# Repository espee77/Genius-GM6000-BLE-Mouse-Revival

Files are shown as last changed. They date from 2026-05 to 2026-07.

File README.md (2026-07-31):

# Reviving a Classic: Genius GM-6000 Wireless BLE / Wired USB / Air Mouse Conversion

This project is an open-source hardware and firmware conversion for the classic Genius GM-6000 mechanical ball mouse.



## History

Introduced in the late 1980s, the Genius GM-6000 was one of the flagship serial mice from [KYE Systems](https://www.geniusnet.com/en) under its Genius brand. At a time when the computer mouse was becoming an essential PC peripheral, the [Genius GM-6000](http://www.tcocd.de/Pictures/Peripheral/Genius/Genius.shtml) stood out with its robust optomechanical design, dynamic resolution technology, and support for both Microsoft and Mouse Systems serial protocols. Bundled with graphics software including Menu Maker and Dr. Halo/Dr. Genius, it was marketed as a premium mouse for both business and graphics applications.

By 1989, Genius advertisements described the company as "the largest selling mouse in Europe," with the GM-6000 featured prominently in its international marketing campaigns. Contemporary reviews also praised the mouse for its accuracy, compatibility, and comprehensive software bundle.

More than three decades later, the GM-6000 is still appreciated by collectors and retro-computing enthusiasts for its solid construction and durable mechanical tracking system. This project preserves those original mechanics while replacing the obsolete electronics with modern Bluetooth Low Energy technology, a rechargeable battery, and optional Air Mouse functionality.

---

## The Goal

The goal of this project is to preserve the look, feel, and mechanics of the original Genius GM-6000 while replacing its obsolete electronics with a modern Bluetooth Low Energy (BLE) system and adding Air Mouse functionality.

Genius-GM6000

Instead of replacing the original ball mechanism with a modern optical sensor, this project preserves the original encoder wheels and tracking mechanics. A custom infrared optical detection system using IR LEDs and phototransistors reads the original quadrature encoders, maintaining the unique feel and behavior of the original mouse.

At the heart of the conversion is a custom PCB based on the [**Seeed Studio XIAO nRF52840 Sense**](https://wiki.seeedstudio.com/XIAO_BLE/), providing Bluetooth LE connectivity, rechargeable Li-Po battery support, intelligent power management, and modern firmware—all while fitting completely inside the original mouse shell.

Genius-GM6000

If this project inspires someone to restore vintage hardware, learn electronics, or build an even better version, then it has already achieved its goal. Contributions, suggestions, forks, and improvements are always welcome.

---

# Project Goals

* Preserve the original appearance of the mouse
* Preserve the original ball and encoder mechanics
* Replace the original electronics with a modern custom PCB
* Add wireless Bluetooth Low Energy (BLE) connectivity
* Integrate a rechargeable Li-Po battery
* Keep both hardware and firmware fully open source

Genius-GM6000

---

# Features

## Ball Mouse

* Bluetooth Low Energy (BLE) HID and wired USB HID support
* Original mechanical ball tracking
* Original infrared quadrature encoder system
* Adjustable cursor speed
* Three original mouse buttons
* Hold the middle button while moving the mouse to scroll smoothly
* Independent sensitivity settings for BLE and USB modes

## Air Mouse

* Automatic Air Mouse mode in both BLE and USB operation
* Automatic switching based on mouse orientation
* Motion smoothing, tremor reduction, and spike filtering
* Full button support while in Air Mouse mode

## Bluetooth

* Compatible with Windows, macOS, Linux, Android, and iPadOS
* Automatic BLE reconnection
* Bluetooth Battery Service (battery level reporting)
* Optimized BLE connection parameters for responsive cursor movement

## Power Management

* Rechargeable Li-Po battery
* Intelligent multi-stage power management
* Automatic IR LED power control
* Light Sleep and Deep Sleep modes for maximum battery life
* Automatic wake-up from movement, IMU motion (during Light Sleep), or button press (from Deep Sleep)

## Hardware

* Custom PCB designed specifically for the GM-6000
* Based on the Seeed Studio XIAO nRF52840 Sense
* Preserves the original buttons and tracking hardware
* Compact design that fits completely inside the original enclosure

---

# Using the Mouse

Despite its modern electronics, the converted GM-6000 is designed to preserve the familiar feel of the original mouse while adding modern wireless features and intelligent power management.

## Ball Mouse

The original mechanical ball, encoder wheels, and tracking mechanism are fully preserved. Cursor movement is generated from the original quadrature encoders, maintaining the characteristic feel of the original GM-6000.

## Scrolling

Since the original mouse has no scroll wheel, scrolling is performed by holding the **middle mouse button** while moving the mouse forward or backward. This allows smooth scrolling without altering the mouse's original appearance.

## Air Mouse

Rotating the mouse onto its side automatically activates **Air Mouse Mode**. The built-in IMU controls the cursor, making the mouse suitable for presentations or media control.

Switching between Ball Mouse and Air Mouse modes is completely automatic—no switches or software are required.

## USB & Bluetooth

The mouse operates as both a wired USB mouse and a Bluetooth Low Energy mouse. Connecting a USB cable automatically enables wired operation, while disconnecting it returns the mouse to Bluetooth mode.

## Intelligent Sleep Modes

To maximize battery life, the firmware automatically manages power consumption.

| Mode | Description |
|---|---|
| **Active** | Full performance while the mouse is in use. |
| **Light Sleep** | Infrared tracking is powered down while remaining ready to wake almost instantly. |
| **Deep Sleep** | Bluetooth disconnects and the mouse enters its lowest power state. |

The mouse automatically wakes from movement, IMU motion (during Light Sleep), or a button press (from Deep Sleep).

## Battery

Battery level is continuously monitored and reported through the Bluetooth Battery Service, allowing supported operating systems to display the remaining battery percentage.

## Factory Reset

If you experience Bluetooth pairing or connection problems, the firmware includes a built-in **Factory Reset** function.

With the mouse powered off, press and hold the **left**, **middle**, and **right** mouse buttons simultaneously while turning the mouse on. Keep all three buttons pressed for approximately **5 seconds** until the status LEDs indicate that the reset has started. The mouse will erase all stored Bluetooth pairing information, saved settings, usage statistics, battery statistics, and internal storage before automatically rebooting.

After a Factory Reset, remove the mouse from your computer's Bluetooth device list (if previously paired) and pair it again as a new device.

---

# Repository Contents

* [Firmware Installation Manual](Firmware%20installation%20manual.md)
* [Bill of material](https://github.com/espee77/Genius-GM6000-BLE-Mouse-Revival/blob/main/V1.0/Bill%20of%20Materials%20(BOM))
* [KiCad 10 project files](https://github.com/espee77/Genius-GM6000-BLE-Mouse-Revival/tree/main/V1.0/KICAD)
* [Schematics](https://github.com/espee77/Genius-GM6000-BLE-Mouse-Revival/tree/main/V1.0/Schematic)
* [Datasheets](https://github.com/espee77/Genius-GM6000-BLE-Mouse-Revival/tree/main/V1.0/Datasheets)
* [Firmware source code](https://github.com/espee77/Genius-GM6000-BLE-Mouse-Revival/tree/main/V1.01/Firmware)
* [JLCPCB zip file for board ordering](https://github.com/espee77/Genius-GM6000-BLE-Mouse-Revival/tree/main/V1.0/JLCPCB)
* [3D CAD files](https://github.com/espee77/Genius-GM6000-BLE-Mouse-Revival/tree/main/V1.0/3D%20files/Step214)
* [Pictures with assembly notes](https://github.com/espee77/Genius-GM6000-BLE-Mouse-Revival/tree/main/V1.0/Pictures%20with%20assembly%20notes)

---

# Why Open Source?

This project started as a fun way to combine retro hardware with modern electronics while preserving a classic piece of computer history.

By making both the hardware and firmware open source, I hope others can learn from it, improve the design, or use it as the foundation for their own retro hardware projects.

Contributions are always welcome, whether they involve hardware improvements, firmware development, documentation, testing, or entirely new ideas.

---

# Current Status

- **[V1.0 – Stable Release](https://github.com/espee77/Genius-GM6000-BLE-Mouse-Revival/tree/main/V1.01)**
- Second-generation custom PCB completed
- Stable Bluetooth Low Energy (BLE) HID firmware
- Reliable deep-sleep wake and automatic BLE reconnection
- Ball Mouse mode fully functional
- Air Mouse mode fully functional
- USB wired mouse mode implemented
- Battery monitoring and charging support
- Automatic power management with multi-stage sleep modes
- Built-in Factory Reset and diagnostic tools
- Extensively tested in daily use
- Optimized Bluetooth performance, responsiveness, and power consumption

---

# Disclaimers

* This is an experimental hobby project.
* Use the provided files and information entirely at your own risk.
* Li-Po batteries and electronic modifications can be hazardous if handled improperly. Always follow appropriate safety precautions.
* This hardware will not fit the Genius GM-6 which differs slightly from the GM-6000 (encoder positions, contact roller size, and rear switch).

---
Genius-GM6000

# Acknowledgements

This project is an independent, community-created restoration effort. The CAD models were created by measuring an original Genius GM-6000 mouse and are not based on or derived from original manufacturer CAD data. "Genius" is a trademark of its respective owner and is used solely to identify the compatible product.
Special thanks to the retro hardware, maker, and open-source communities whose shared knowledge, documentation, and projects made this conversion possible.



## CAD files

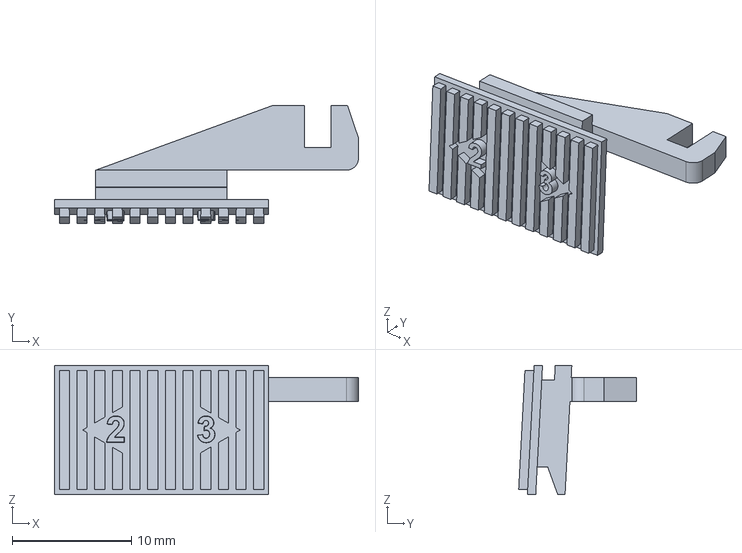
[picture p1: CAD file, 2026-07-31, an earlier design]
V1.0/3D files/Step214/Genius_GM-6000_Slide_Button_V0.1.stp
25.4 x 9.85 x 10.8 mm

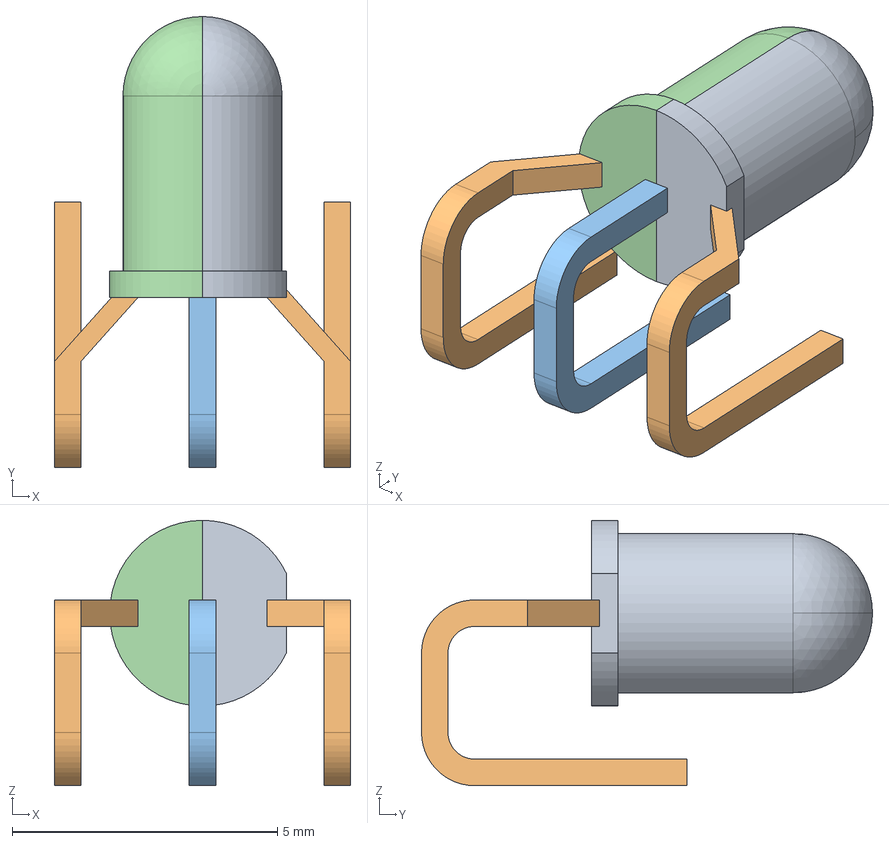
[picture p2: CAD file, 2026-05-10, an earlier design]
V1.0/KICAD/3D data/Genius_GM-6000_BLE_LED_3009R1B2C-DSA_V0.1.stp
5.58 x 8.50 x 5.00 mm

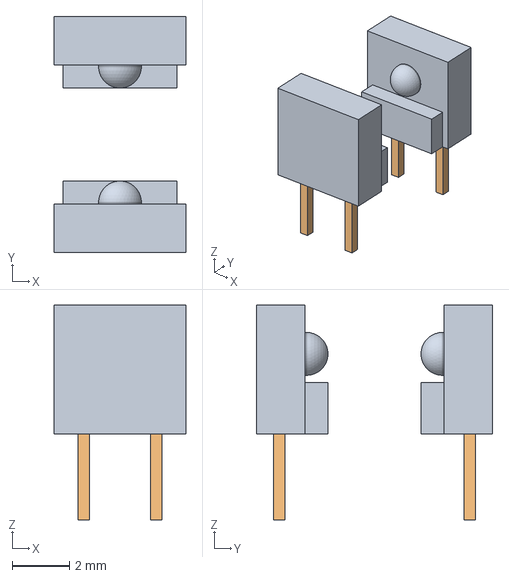
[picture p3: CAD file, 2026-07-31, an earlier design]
V1.0/3D files/Step214/Genius_GM-6000_IR928_PT928_V0.1.stp
4.60 x 8.25 x 7.50 mm

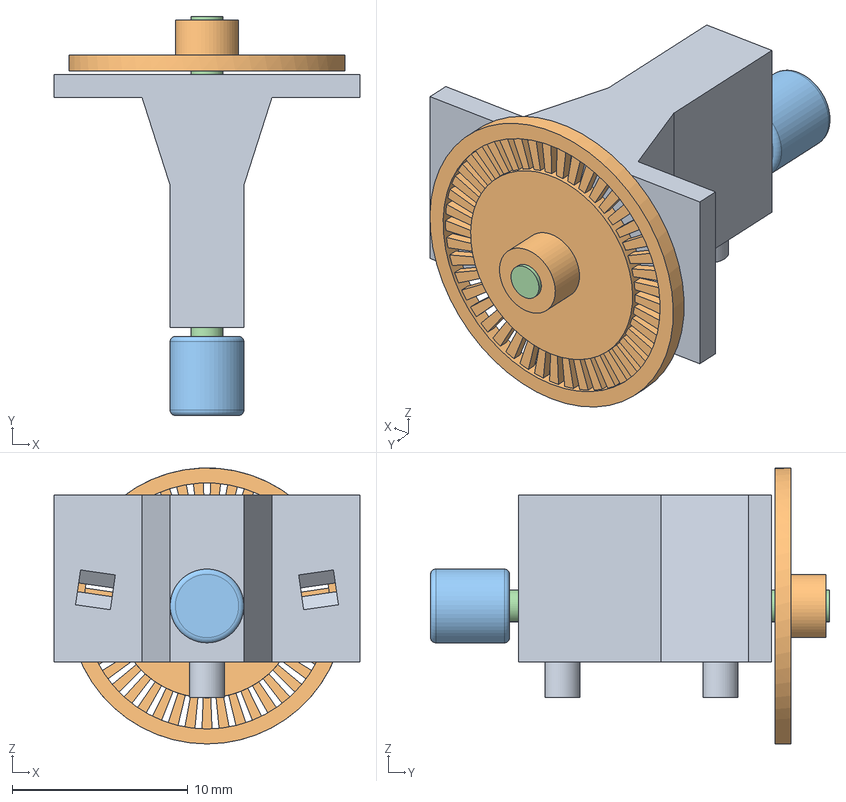
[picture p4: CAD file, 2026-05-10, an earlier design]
V1.0/KICAD/3D data/Genius_GM-6000_Encoder_Wheel_V0.1.stp
17.4 x 22.7 x 15.7 mm

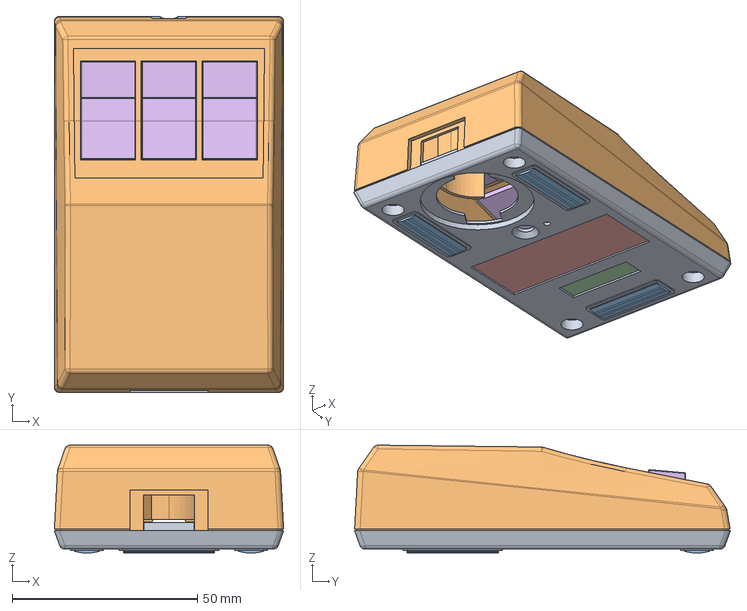
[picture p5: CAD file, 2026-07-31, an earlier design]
V1.0/3D files/Step214/Genius_GM-6000_Housing_V0.3.stp
62.0 x 101.6 x 29.1 mm

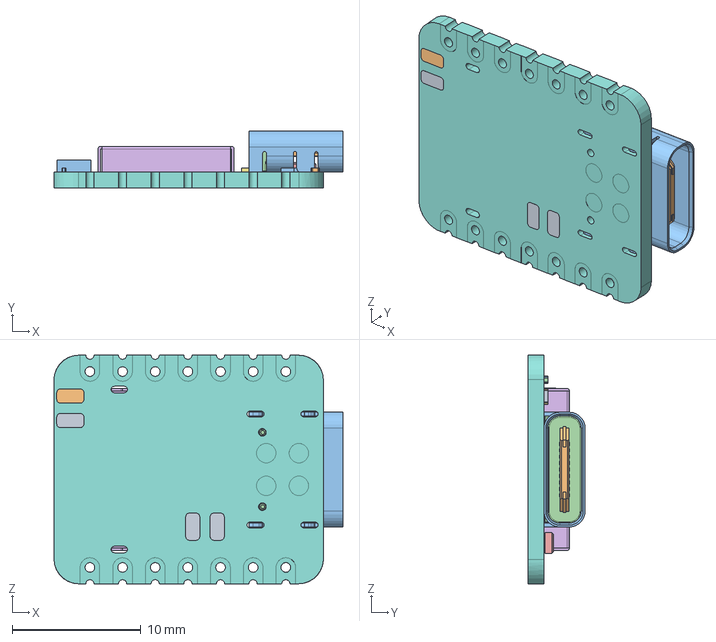
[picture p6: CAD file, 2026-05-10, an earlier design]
V1.0/KICAD/3D data/Genius_GM-6000_XIAO-nRF52840_Sense_V0.1.stp
22.5 x 4.46 x 17.8 mm

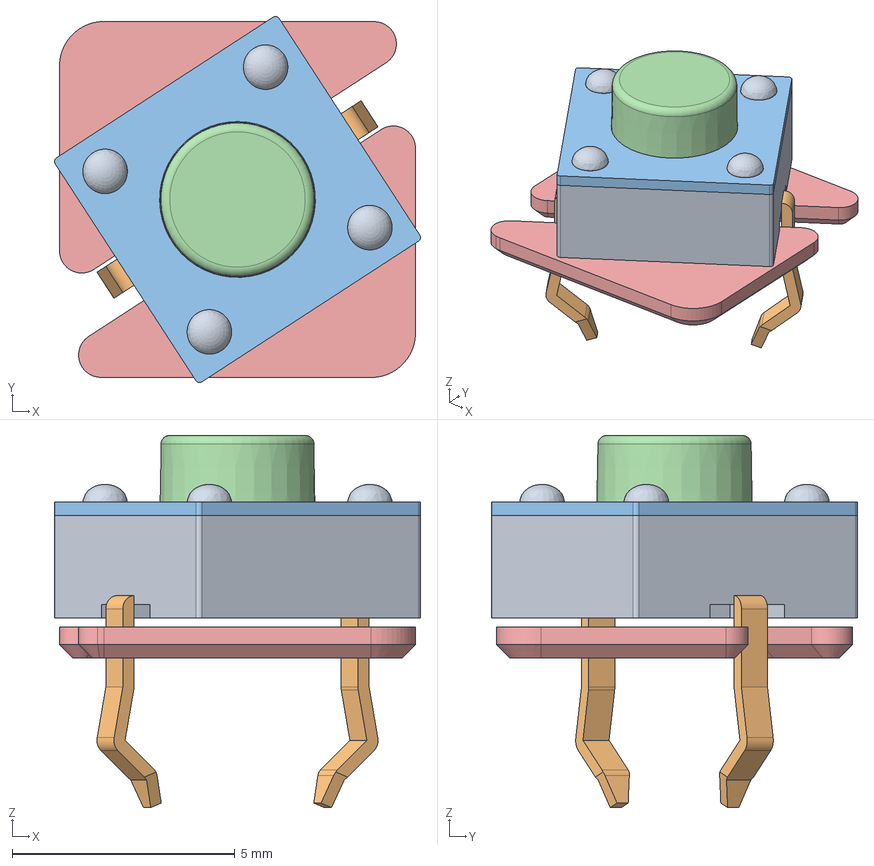
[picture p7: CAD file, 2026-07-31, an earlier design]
V1.0/3D files/Step214/Genius_GM-6000_Tact_Switch_Silent_6x6_V0.1.stp
8.22 x 8.22 x 8.36 mm

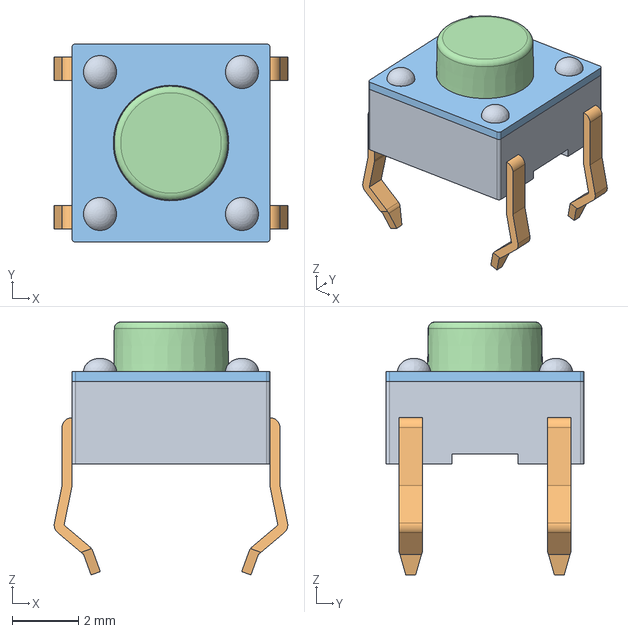
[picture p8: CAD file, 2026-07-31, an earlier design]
V1.0/3D files/Step214/Genius_GM-6000_Tact_Switch_4.3_6x6_V0.1.stp
7.08 x 6.00 x 7.66 mm

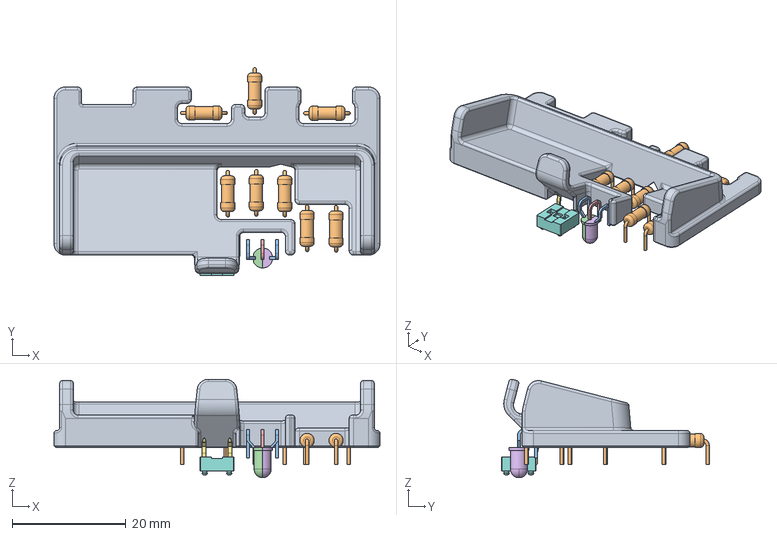
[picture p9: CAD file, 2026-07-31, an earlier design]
V1.0/3D files/Step214/Genius_GM-6000_LiPo_Holder_V0.1.stp
57.2 x 36.4 x 17.3 mm

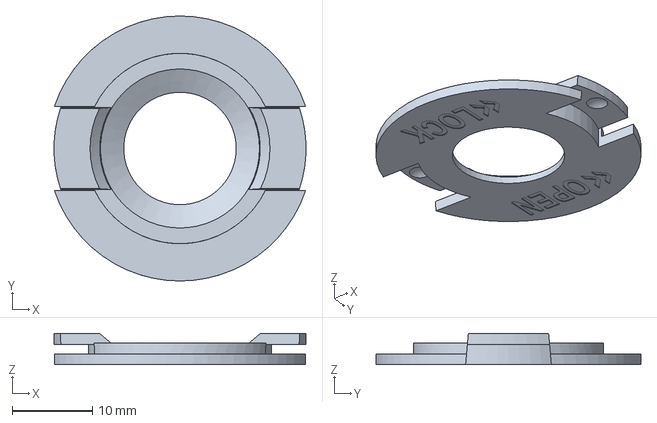
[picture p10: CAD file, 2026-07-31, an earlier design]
V1.0/3D files/Step214/Genius_GM-6000_Ball_Lock_V0.1.stp
31.4 x 33.0 x 3.90 mm

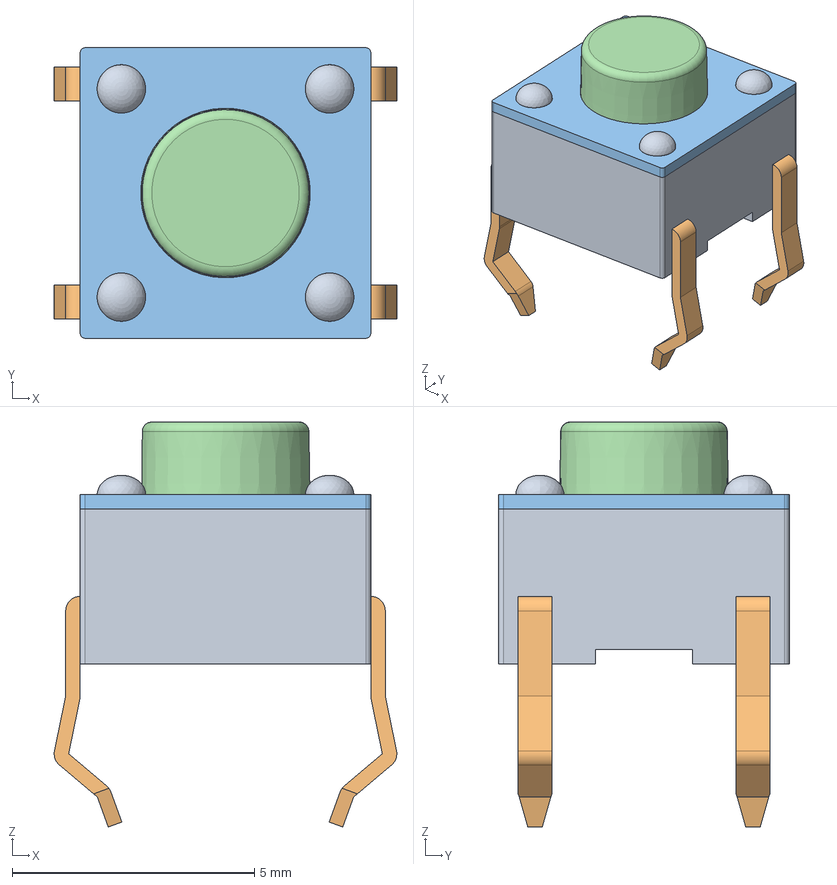
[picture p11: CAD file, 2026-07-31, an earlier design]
V1.0/3D files/Step214/Genius_GM-6000_Tact_Switch_5.0_6x6_V0.1.stp
7.08 x 6.00 x 8.36 mm

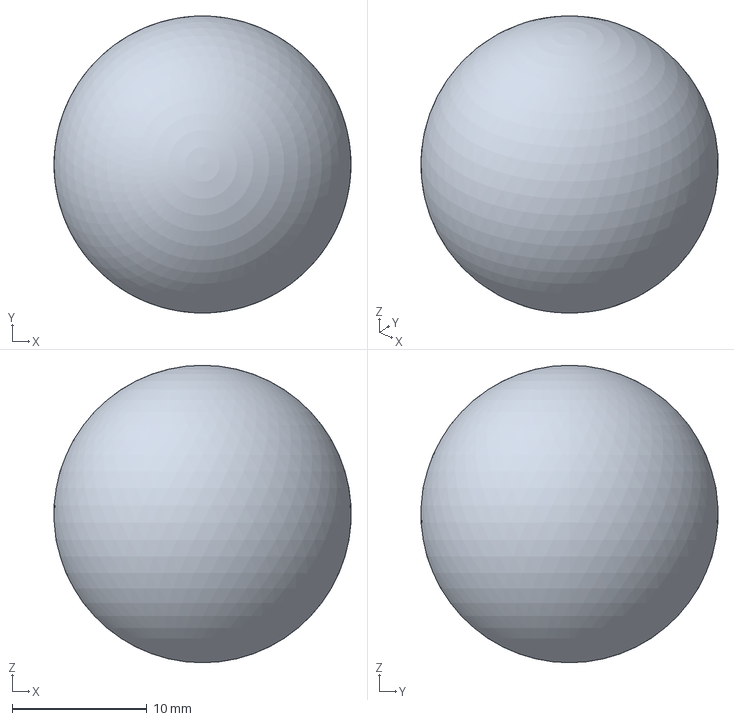
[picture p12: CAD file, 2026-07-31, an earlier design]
V1.0/3D files/Step214/Genius_GM-6000_Ball_V0.1.stp
22.1 x 22.1 x 22.1 mm

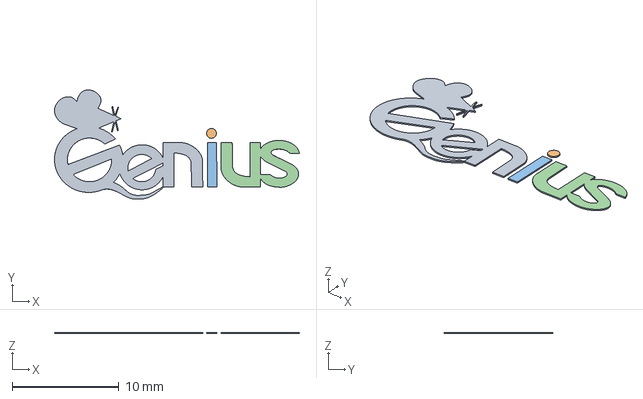
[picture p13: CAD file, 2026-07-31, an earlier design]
V1.0/3D files/Step214/Genius_GM-6000_Logo_V0.1.stp
23.0 x 10.2 x 0.108 mm

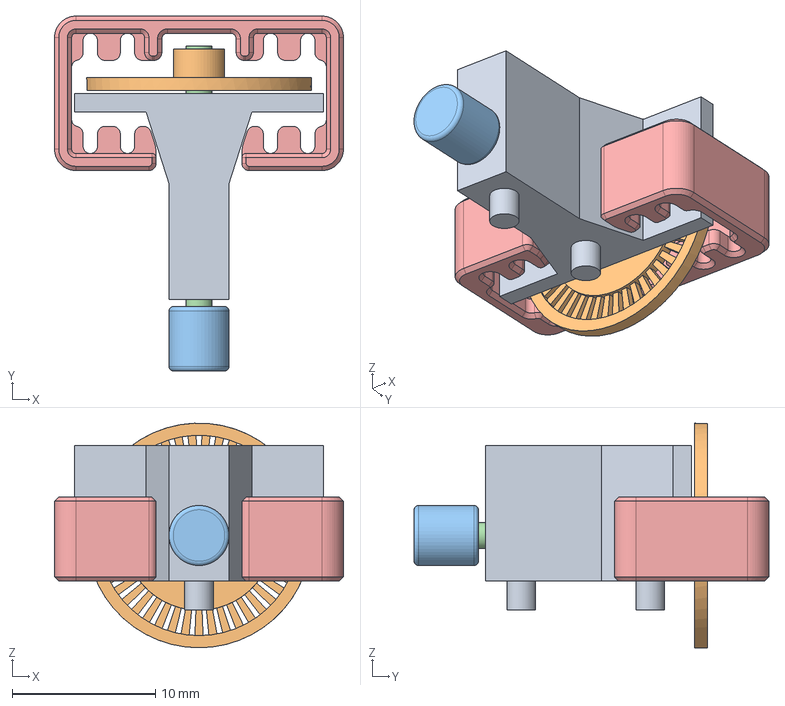
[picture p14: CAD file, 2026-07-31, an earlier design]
V1.0/3D files/Step214/Genius_GM-6000_Encoder_Wheel_V0.2.stp
20.2 x 24.8 x 15.7 mm

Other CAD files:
V1.0/3D files/Step214/Genius_GM-6000_Assy_V1.0.stp
V1.0/3D files/Step214/Genius_GM-6000_XIAO-nRF52840_Sense_V0.1.stp
V1.0/3D files/Step214/Genius_GM-6000_Switch_SS-12D07-VG-4-NS-GA-PA_V0.1.stp
V1.0/3D files/Step214/Genius_GM-6000_BLE_LED_3009R1B2C-DSA_V0.1.stp
V1.0/3D files/Step214/Genius_GM-6000_LiPo_Cardo_Scala_Rider_G4_800mAh_V0.1.stp

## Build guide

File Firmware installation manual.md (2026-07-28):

# Installing the GM-6000 Firmware

> [!IMPORTANT]
> This guide is for the **Genius GM-6000 BLE Mouse Revival** project using the **Seeed Studio XIAO nRF52840 Sense**.
>
> It assumes you are using **Windows 10 or Windows 11**.

This guide explains how to install the latest firmware on your GM-6000 mouse using PlatformIO.

**No programming experience is required.**

> [!NOTE]
> **Tested with**
>
> * Windows 11
> * Visual Studio Code 1.104 or newer
> * PlatformIO IDE 3.x

---

## Table of Contents

* [What You Need](#requirements)
* [Step 1 – Install Visual Studio Code](#install-vscode)
* [Step 2 – Install PlatformIO](#install-platformio)
* [Step 3 – Download the Firmware](#download-firmware)
* [Step 4 – Extract the ZIP File](#extract-firmware)
* [Step 5 – Open the Project](#open-project)
* [Step 6 – Connect the Mouse](#connect-mouse)
* [Step 7 – Build the Firmware](#build-firmware)
* [Step 8 – Upload the Firmware](#upload-firmware)
* [Step 9 – Pair the Mouse](#pair-mouse)
* [Reset Bluetooth Pairings](#reset-pairings)
* [Troubleshooting](#troubleshooting)
* [Updating the Firmware](#update-firmware)

---

## What You Need

Before you begin, make sure you have:

* A Windows 10 or Windows 11 computer
* A USB-C **data** cable
* An internet connection
* The latest GM-6000 firmware ZIP file

> [!NOTE]
> Some USB-C cables only provide power. If the mouse is not detected, try another cable.

[Back to Table of Contents](#table-of-contents)

---

## Step 1 – Install Visual Studio Code

PlatformIO runs inside Visual Studio Code.

1. Download [Visual Studio Code](https://code.visualstudio.com/download) from the official website.

2. Run the installer.

3. Accept the default installation settings.

4. Start Visual Studio Code.

> [!IMPORTANT]
> Install **Visual Studio Code**.
>
> Do **not** install the larger application called **Visual Studio**.

[Back to Table of Contents](#table-of-contents)

---

## Step 2 – Install PlatformIO

1. Open Visual Studio Code.

2. Click the **Extensions** icon on the left.

3. Search for:

   ```text
   PlatformIO IDE
   ```

4. Select **PlatformIO IDE** by **PlatformIO**.

5. Click **Install**.

6. Wait for the installation to finish.

7. Restart Visual Studio Code if prompted.

See the official [PlatformIO installation guide](https://platformio.org/install/ide?install=vscode).

> [!TIP]
> You do **not** need to install Python or the Arduino IDE separately.

[Back to Table of Contents](#table-of-contents)

---

## Step 3 – Download the Firmware

Download the latest firmware ZIP file from the project’s **GitHub Releases** page.

Save the ZIP file somewhere easy to find, such as your **Downloads** folder.

[Back to Table of Contents](#table-of-contents)

---

## Step 4 – Extract the ZIP File

Do **not** open the project directly from the ZIP file.

1. Right-click the downloaded ZIP file.

2. Select **Extract All...**

3. Choose a location, for example:

   ```text
   Documents\GM-6000 Firmware
   ```

4. Click **Extract**.

[Back to Table of Contents](#table-of-contents)

---

## Step 5 – Open the Project

1. Open Visual Studio Code.

2. Select:

   **File → Open Folder...**

3. Browse to the extracted firmware folder.

4. Select the folder containing:

   ```text
   platformio.ini
   ```

5. Click **Select Folder**.

6. If Visual Studio Code asks whether you trust the project, click:

   **Trust the Authors**

> [!TIP]
> If you cannot find `platformio.ini`, you probably opened the wrong folder.

The correct project folder should contain files and folders similar to these:

```text
platformio.ini
src
include
lib
```

[Back to Table of Contents](#table-of-contents)

---

## Step 6 – Connect the Mouse

1. Connect the mouse to your computer using a USB-C **data** cable.

2. Turn the mouse on.

Windows should detect the mouse automatically.

[Back to Table of Contents](#table-of-contents)

---

## Step 7 – Build the Firmware

Building the project checks that everything is ready before uploading.

**It does not change anything on the mouse.**

### Method 1 – Project Tasks

1. Click the **PlatformIO** icon, usually shown as an alien-head symbol, in the left sidebar.

2. Expand:

   ```text
   Project Tasks
   ```

3. Expand:

   ```text
   General
   ```

4. Click:

   ```text
   Build
   ```

### Method 2 – Build Button

If a **Build (✓)** button is visible in your PlatformIO interface, you can use that instead.

> [!NOTE]
> The first build may take several minutes.
>
> PlatformIO automatically downloads the compiler, board support package and required libraries during the first build.

When the build finishes successfully, the terminal should end with:

```text
SUCCESS
```

Do **not** continue if the build ends with:

```text
FAILED
```

[Back to Table of Contents](#table-of-contents)

---

## Step 8 – Upload the Firmware

### Method 1 – Project Tasks

1. Open:

   ```text
   Project Tasks
   ```

2. Expand:

   ```text
   General
   ```

3. Click:

   ```text
   Upload
   ```

### Method 2 – Upload Button

If an **Upload (→)** button is visible in your PlatformIO interface, you can use that instead.

PlatformIO will now:

* Build the firmware
* Upload it to the mouse
* Restart the mouse automatically

When the upload is complete, the terminal should end with:

```text
SUCCESS
```

> [!WARNING]
> Do not disconnect the USB cable while the firmware is being uploaded.

[Back to Table of Contents](#table-of-contents)

---

## Step 9 – Pair the Mouse

After uploading:

1. Disconnect the USB cable if you want to use Bluetooth.

2. Turn the mouse off and back on.

3. Open your computer’s Bluetooth settings.

4. Select:

   ```text
   Genius GM-6000 BLE mouse
   ```

5. Complete the pairing process.

Your mouse is now ready to use.

[Back to Table of Contents](#table-of-contents)

---

## Reset Bluetooth Pairings

Use this function if the mouse cannot pair with a new computer or repeatedly connects and disconnects during pairing.

1. Turn the mouse **off**.

2. Press and hold all three mouse buttons:

   * Left mouse button
   * Middle mouse button
   * Right mouse button

3. While holding all three buttons, turn the mouse **on**.

4. Keep holding the buttons for **5 seconds**.

5. Release the buttons.

The mouse will erase all stored Bluetooth pairings and restart automatically.

You can now pair it as a new Bluetooth mouse.

> [!NOTE]
> If your mouse has an external dual-colour status LED installed, the red and blue LEDs will alternate while you hold the buttons.
>
> After the stored pairings have been erased, both colours will flash three times before the mouse restarts.

> [!IMPORTANT]
> You may also need to remove the old mouse entry from your computer’s Bluetooth settings before pairing it again.

[Back to Table of Contents](#table-of-contents)

---

## Troubleshooting

<details>
<summary><strong>The mouse is not detected</strong></summary>

Try the following:

* Make sure you are using a USB-C **data** cable.
* Try another USB port.
* Try another USB cable.
* Disconnect and reconnect the mouse.
* Turn the mouse off and back on.

</details>

<details>
<summary><strong>Enter Bootloader Mode</strong></summary>

If uploading still fails:

1. Leave the mouse connected by USB.

2. Quickly press the **RESET** button on the XIAO **twice**.

3. A new COM port should appear.

4. Try uploading again.

> [!NOTE]
> The COM port number may change when the XIAO enters bootloader mode. This is normal.

See the official [Seeed Studio XIAO nRF52840 documentation](https://wiki.seeedstudio.com/XIAO_BLE/).

</details>

<details>
<summary><strong>PlatformIO reports “Access is denied”</strong></summary>

If you receive an error similar to:

```text
PermissionError: Access is denied
```

Another program is probably already using the serial port.

Close programs such as:

* PlatformIO Serial Monitor
* PuTTY
* Another serial terminal
* Another open instance of Visual Studio Code

Then try uploading again.

</details>

<details>
<summary><strong>PlatformIO uses the wrong COM port</strong></summary>

Normally PlatformIO detects the correct COM port automatically.

If it does not:

1. Open:

   ```text
   platformio.ini
   ```

2. Find or add:

   ```ini
   upload_port =
   ```

3. Set it to the correct COM port, for example:

   ```ini
   upload_port = COM19
   ```

4. Save the file.

5. Try uploading again.

If the COM port changes later, update or remove this line.

> [!NOTE]
> The normal firmware mode and bootloader mode may use different COM port numbers.

</details>

<details>
<summary><strong>The build fails</strong></summary>

If the project does not build:

* Make sure the ZIP file was fully extracted.
* Make sure you opened the folder containing `platformio.ini`.
* Check that your internet connection is working.
* Verify that PlatformIO IDE is installed correctly.
* Restart Visual Studio Code.
* Try building the project again.

If necessary, extract a fresh copy of the firmware ZIP and open the new folder.

</details>

<details>
<summary><strong>The upload succeeds, but Bluetooth pairing fails</strong></summary>

Try the following:

1. Remove the existing **Genius GM-6000 BLE mouse** entry from your computer’s Bluetooth settings.

2. Reset the stored Bluetooth pairings in the mouse by holding the left, middle and right buttons for 5 seconds during startup.

3. Turn the mouse off and back on.

4. Pair the mouse again.

</details>

<details>
<summary><strong>The mouse repeatedly connects and disconnects</strong></summary>

This can be caused by an old or incompatible Bluetooth pairing.

1. Remove the mouse from the computer’s Bluetooth settings.

2. Reset the stored pairings in the mouse.

3. Restart the computer’s Bluetooth adapter if necessary.

4. Pair the mouse again as a new device.

</details>

[Back to Table of Contents](#table-of-contents)

---

## Updating the Firmware

To install a newer firmware version:

1. Download the new firmware ZIP file.

2. Extract it to a new folder.

3. Open the new project folder in Visual Studio Code.

4. Build the project.

5. Upload the firmware.

The mouse will restart automatically with the new firmware.

> [!TIP]
> Keep the previous working firmware ZIP file as a backup until you have tested the new version.

[Back to Table of Contents](#table-of-contents)

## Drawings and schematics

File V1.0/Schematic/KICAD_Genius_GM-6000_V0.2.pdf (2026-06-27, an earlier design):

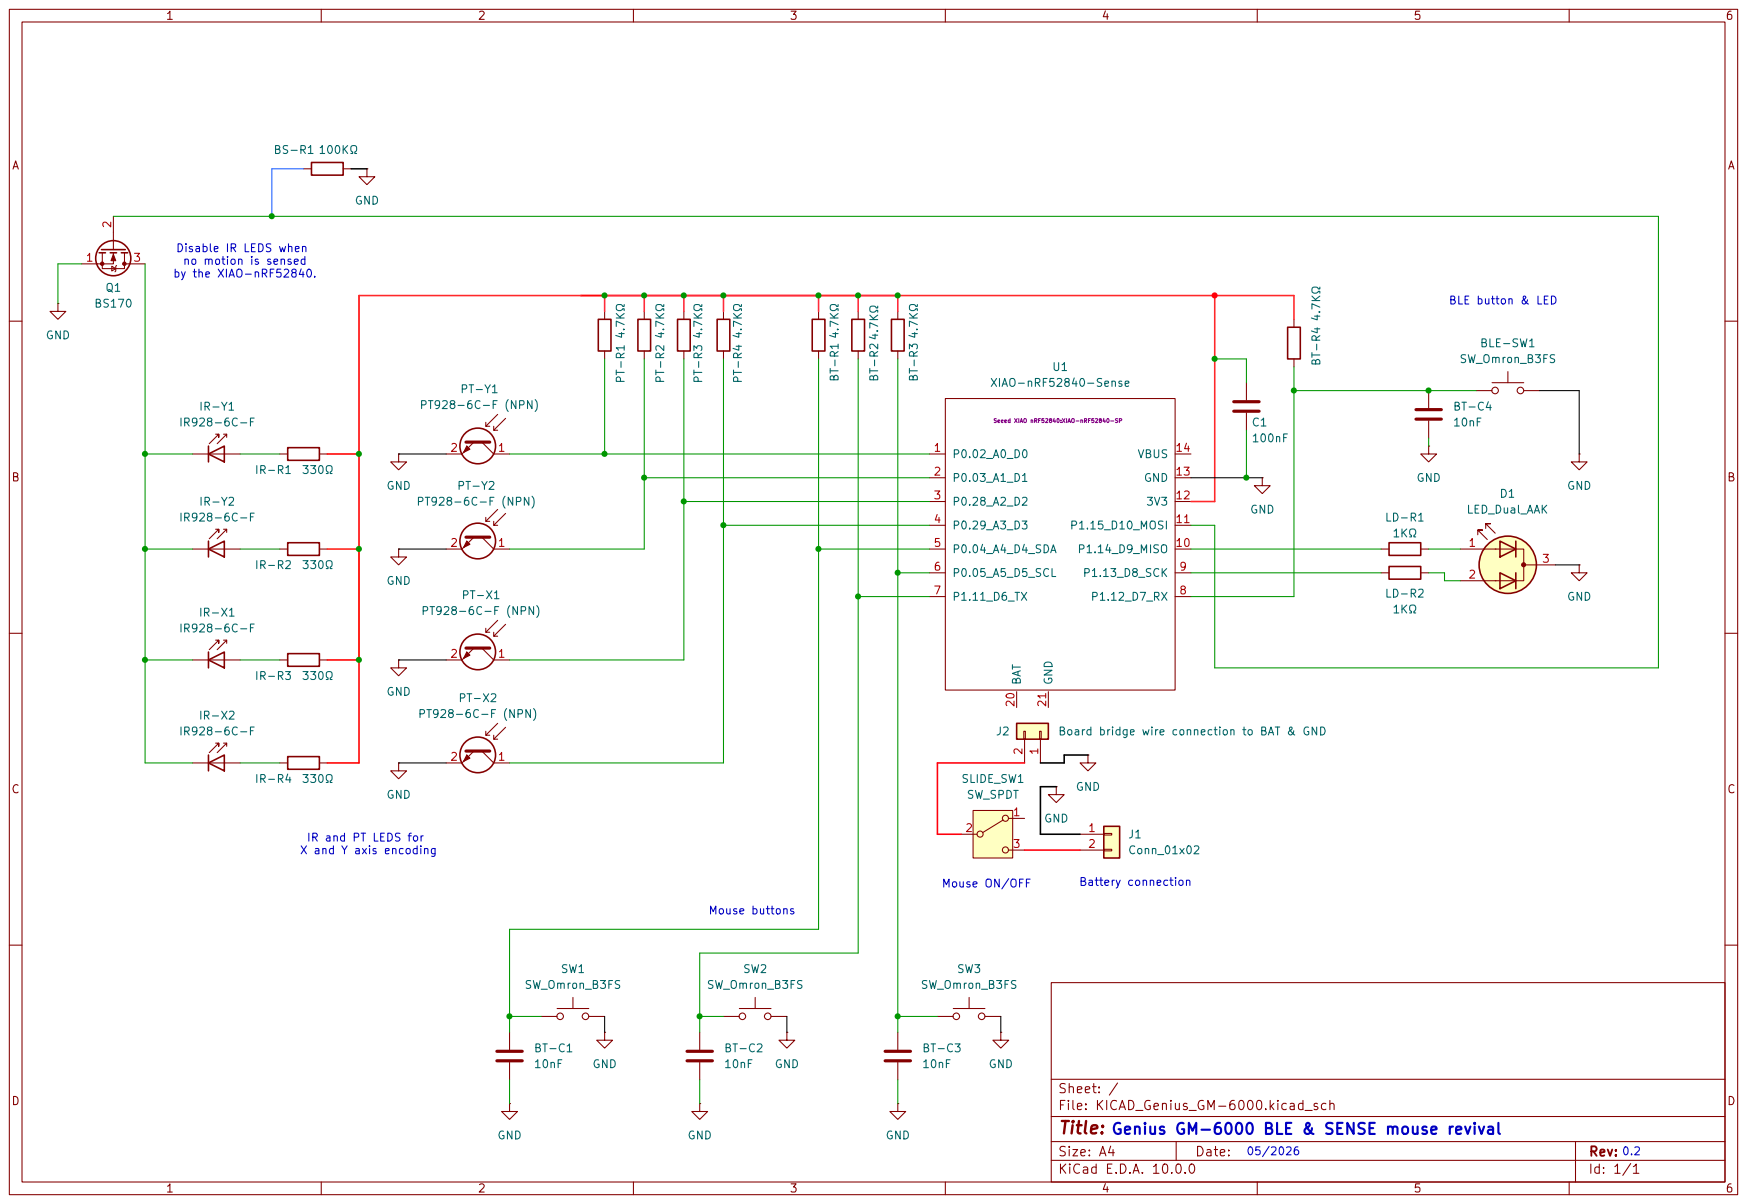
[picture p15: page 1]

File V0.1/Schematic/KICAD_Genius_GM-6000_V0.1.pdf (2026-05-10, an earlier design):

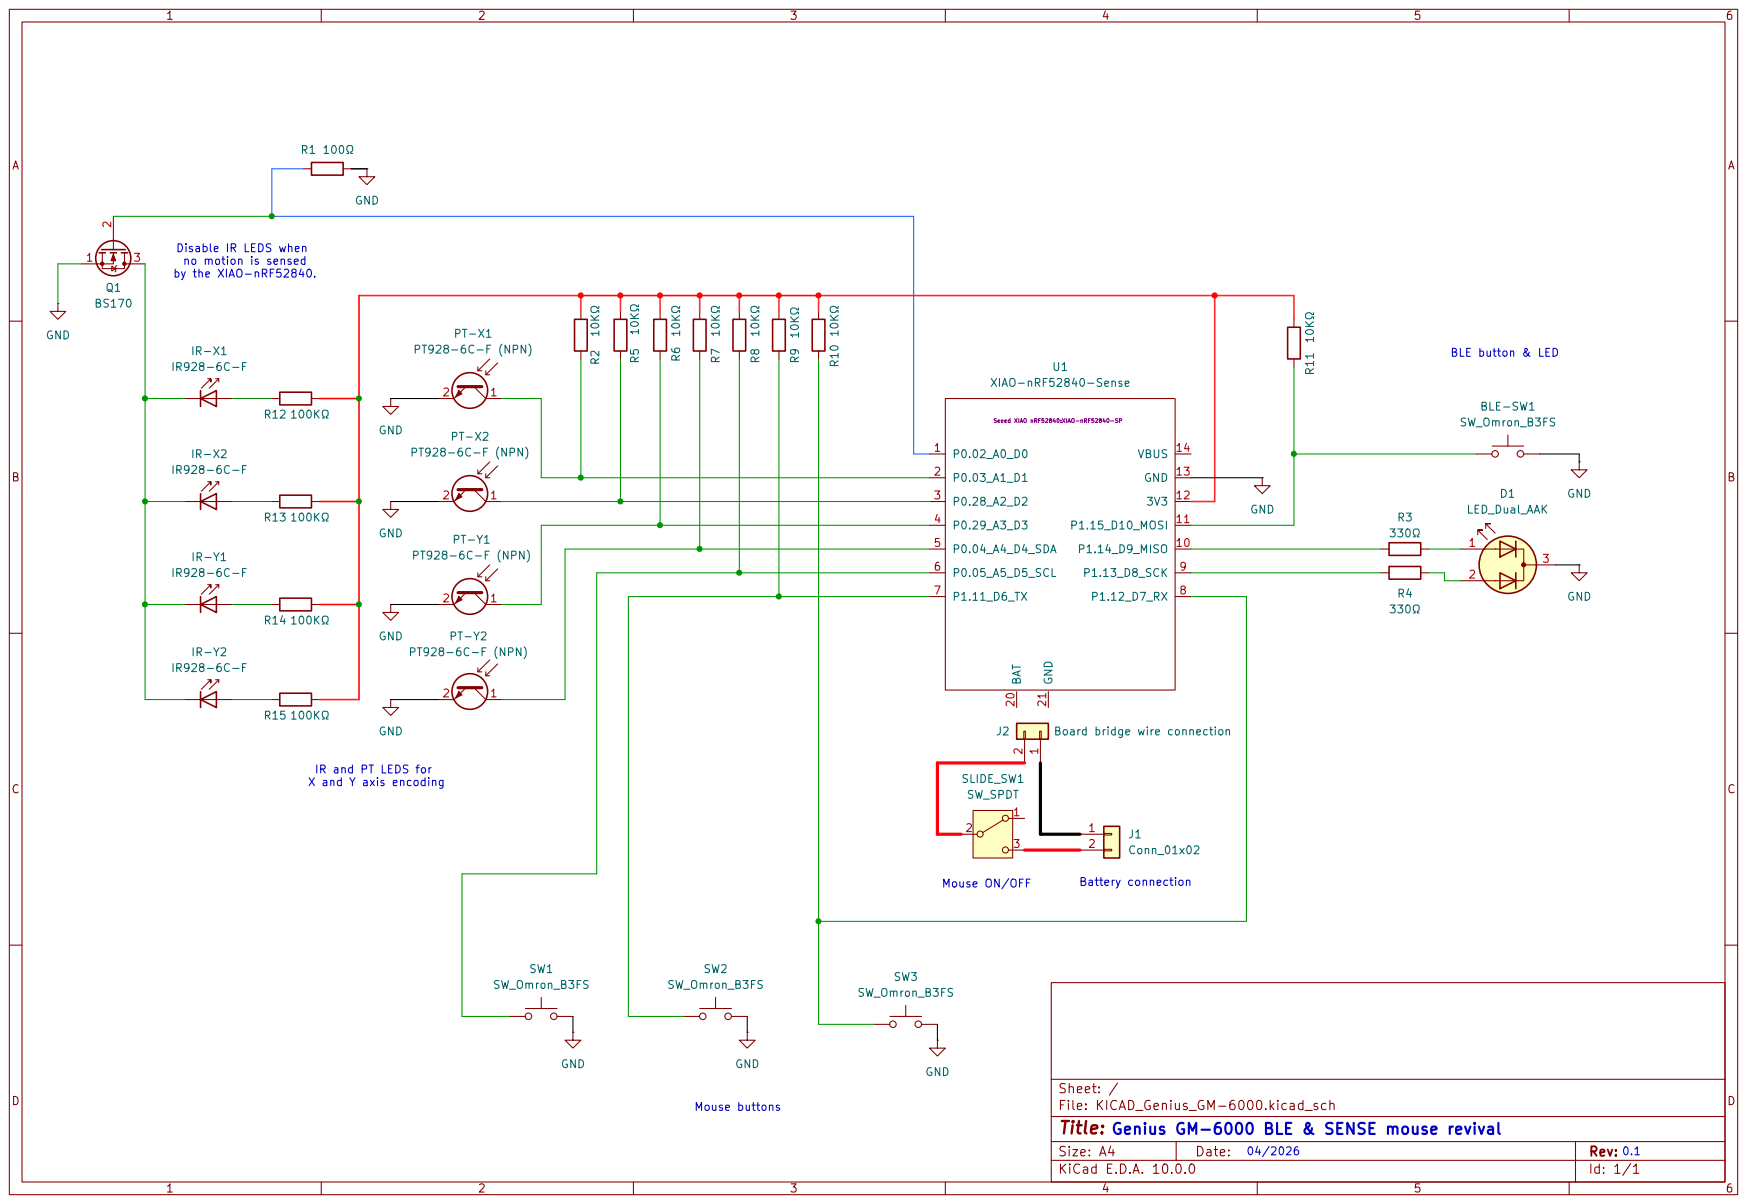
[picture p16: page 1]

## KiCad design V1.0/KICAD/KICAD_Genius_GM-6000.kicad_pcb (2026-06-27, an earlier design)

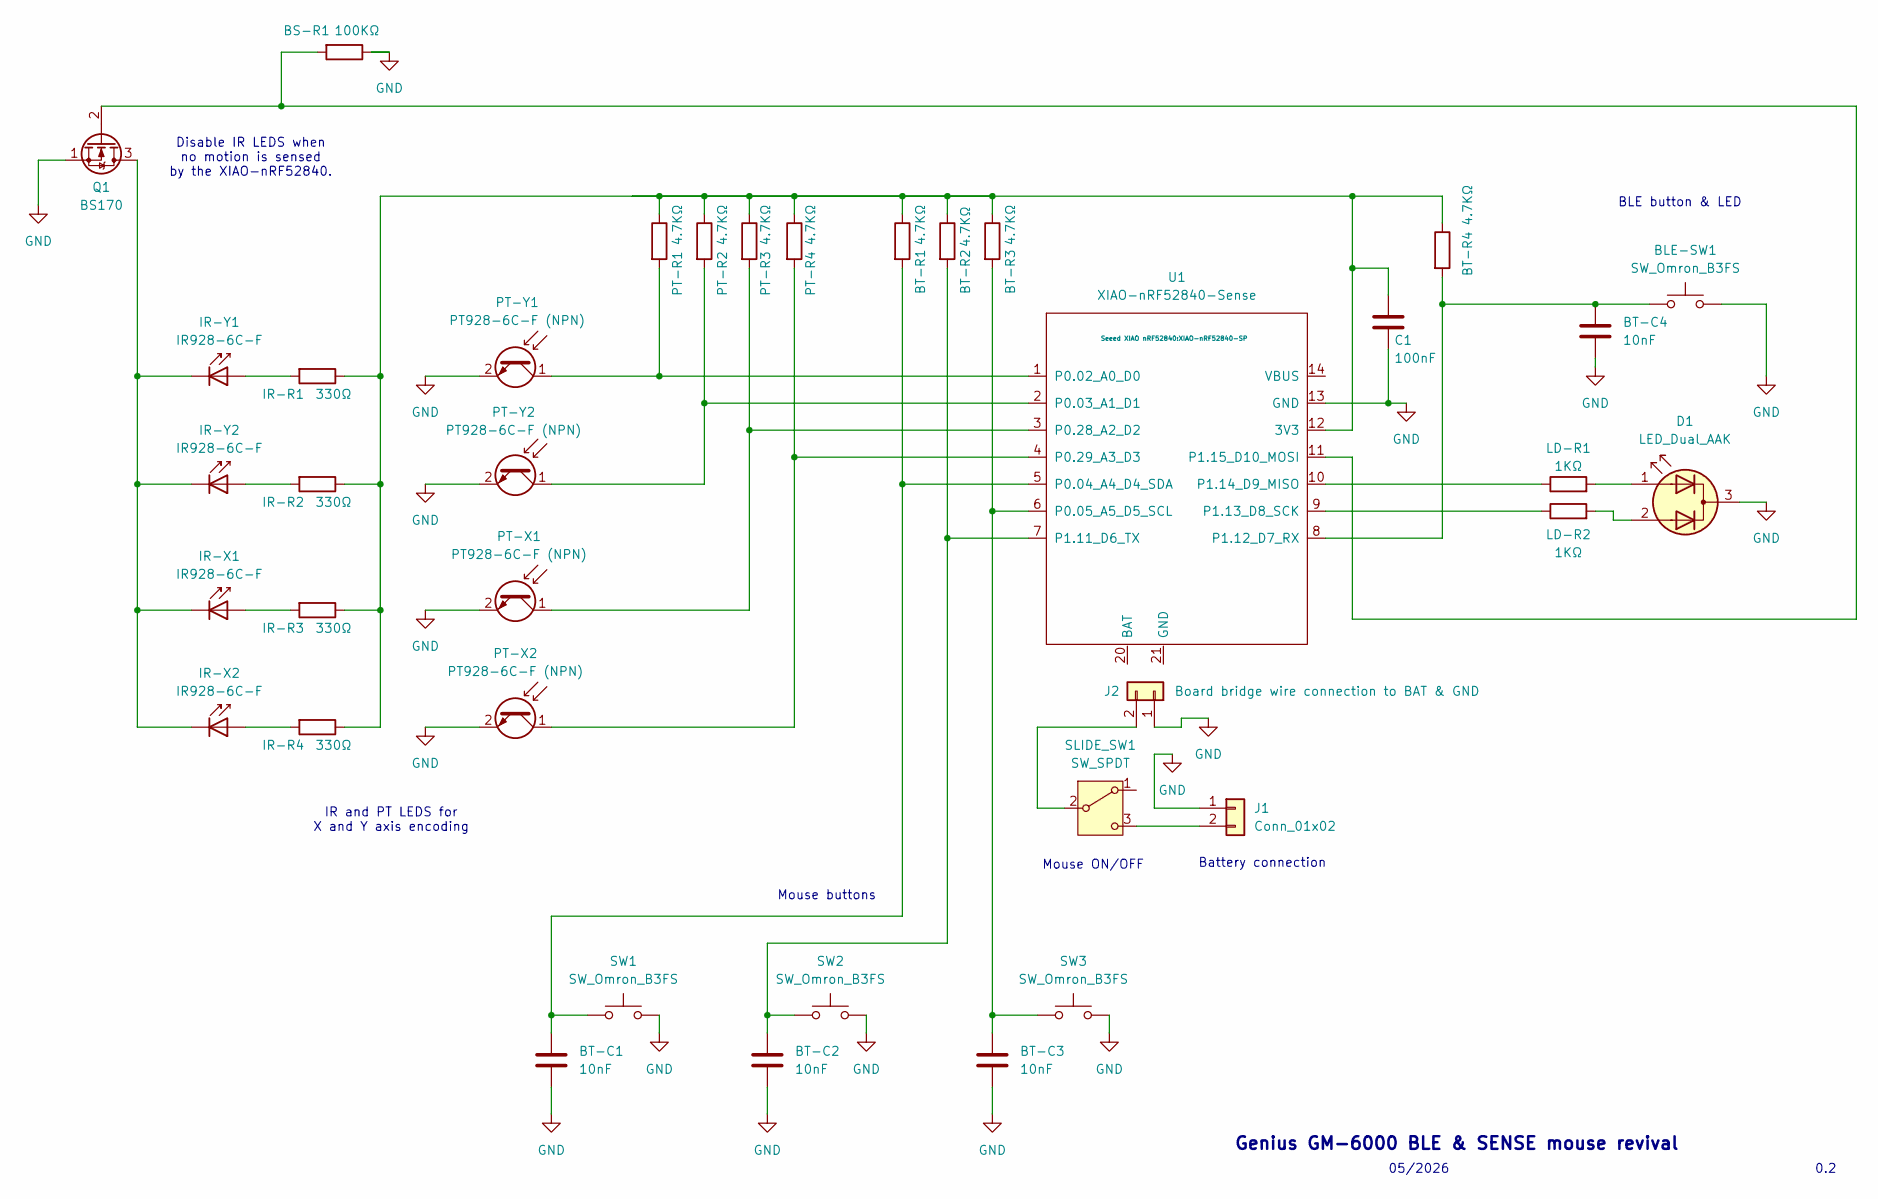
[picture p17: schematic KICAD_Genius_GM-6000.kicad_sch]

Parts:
BLE-SW1: SW_Omron_B3FS; SW_PUSH_6mm
BS-R1: 100KΩ; R_Axial_DIN0207_L6.3mm_D2.5mm_P7.62mm_Horizontal
BT-C1, BT-C2, BT-C3, BT-C4: 10nF; C_Disc_D5.0mm_W2.5mm_P2.50mm
BT-R1, BT-R2, BT-R3, BT-R4: 4.7KΩ; R_Axial_DIN0207_L6.3mm_D2.5mm_P7.62mm_Horizontal
C1: 100nF; C_Disc_D5.0mm_W2.5mm_P2.50mm
D1: LED_Dual_AAK; LED_D3.0mm-3
IR-R1, IR-R2, IR-R3, IR-R4: 330Ω; R_Axial_DIN0207_L6.3mm_D2.5mm_P7.62mm_Horizontal
IR-X1, IR-X2: IR928-6C-F; LED_SideEmitter_Rectangular_W4.5mm_H1.6mm
IR-Y1, IR-Y2: IR928-6C-F; LED_SideEmitter_Rectangular_W4.5mm_H1.6mm
J1: Conn_01x02
J2: Board bridge wire connection to BAT & GND; PinHeader_1x02_P2.54mm_Vertical
LD-R1, LD-R2: 1KΩ; R_Axial_DIN0207_L6.3mm_D2.5mm_P7.62mm_Horizontal
PT-R1, PT-R2, PT-R3, PT-R4: 4.7KΩ; R_Axial_DIN0207_L6.3mm_D2.5mm_P7.62mm_Horizontal
PT-X1, PT-X2: PT928-6C-F (NPN); Osram_LPT80A
PT-Y1, PT-Y2: PT928-6C-F (NPN); Osram_LPT80A
Q1: BS170; TO-92L_Inline_Wide
SLIDE_SW1: SW_SPDT; SW_Slide_SPDT_Straight_CK_OS102011MS2Q
SW1, SW2, SW3: SW_Omron_B3FS; SW_PUSH_6mm
U1: XIAO-nRF52840-Sense; XIAO-nRF52840-SP

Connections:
GND: BLE-SW1.2, BS-R1.1, BT-C1.2, BT-C2.2, BT-C3.2, BT-C4.2, C1.2, D1.3 (K), J1.1, J2.1, PT-X1.2 (E), PT-X2.2 (E), PT-Y1.2 (E), PT-Y2.2 (E), Q1.1 (S), SW1.2, SW2.2, SW3.2, U1.13 (GND)
unnamed: D1.1 (A1), LD-R1.2
unnamed: D1.2 (A2), LD-R2.2
unnamed: IR-R3.2, IR-X1.2 (A)
unnamed: IR-X1.1 (K), IR-X2.1 (K), IR-Y1.1 (K), IR-Y2.1 (K), Q1.3 (D)
unnamed: IR-R4.2, IR-X2.2 (A)
unnamed: IR-R1.2, IR-Y1.2 (A)
unnamed: IR-R2.2, IR-Y2.2 (A)
unnamed: J1.2, SLIDE_SW1.3 (C)
unnamed: J2.2, SLIDE_SW1.2 (B)
unnamed: PT-R3.2, PT-X1.1 (C), U1.3 (P0.28_A2_D2)
unnamed: PT-R4.2, PT-X2.1 (C), U1.4 (P0.29_A3_D3)
unnamed: PT-R1.2, PT-Y1.1 (C), U1.1 (P0.02_A0_D0)
unnamed: PT-R2.2, PT-Y2.1 (C), U1.2 (P0.03_A1_D1)
unnamed: BS-R1.2, Q1.2 (G), U1.11 (P1.15_D10_MOSI)
unnamed: BT-R1.1, BT-R2.1, BT-R3.1, BT-R4.1, C1.1, IR-R1.1, IR-R2.1, IR-R3.1, IR-R4.1, PT-R1.1, PT-R2.1, PT-R3.1, PT-R4.1, U1.12 (3V3)
unnamed: BT-C1.1, BT-R1.2, SW1.1, U1.5 (P0.04_A4_D4_SDA)
unnamed: BT-C3.1, BT-R3.2, SW3.1, U1.6 (P0.05_A5_D5_SCL)
unnamed: BT-C2.1, BT-R2.2, SW2.1, U1.7 (P1.11_D6_TX)
unnamed: BLE-SW1.1, BT-C4.1, BT-R4.2, U1.8 (P1.12_D7_RX)
unnamed: LD-R2.1, U1.9 (P1.13_D8_SCK)
unnamed: LD-R1.1, U1.10 (P1.14_D9_MISO)

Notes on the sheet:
0.2
Battery connection
Mouse buttons
IR and PT LEDS for X and Y axis encoding
05/2026
Mouse ON/OFF
Genius GM-6000 BLE & SENSE mouse revival
Disable IR LEDS when no motion is sensed by the XIAO-nRF52840.
BLE button & LED

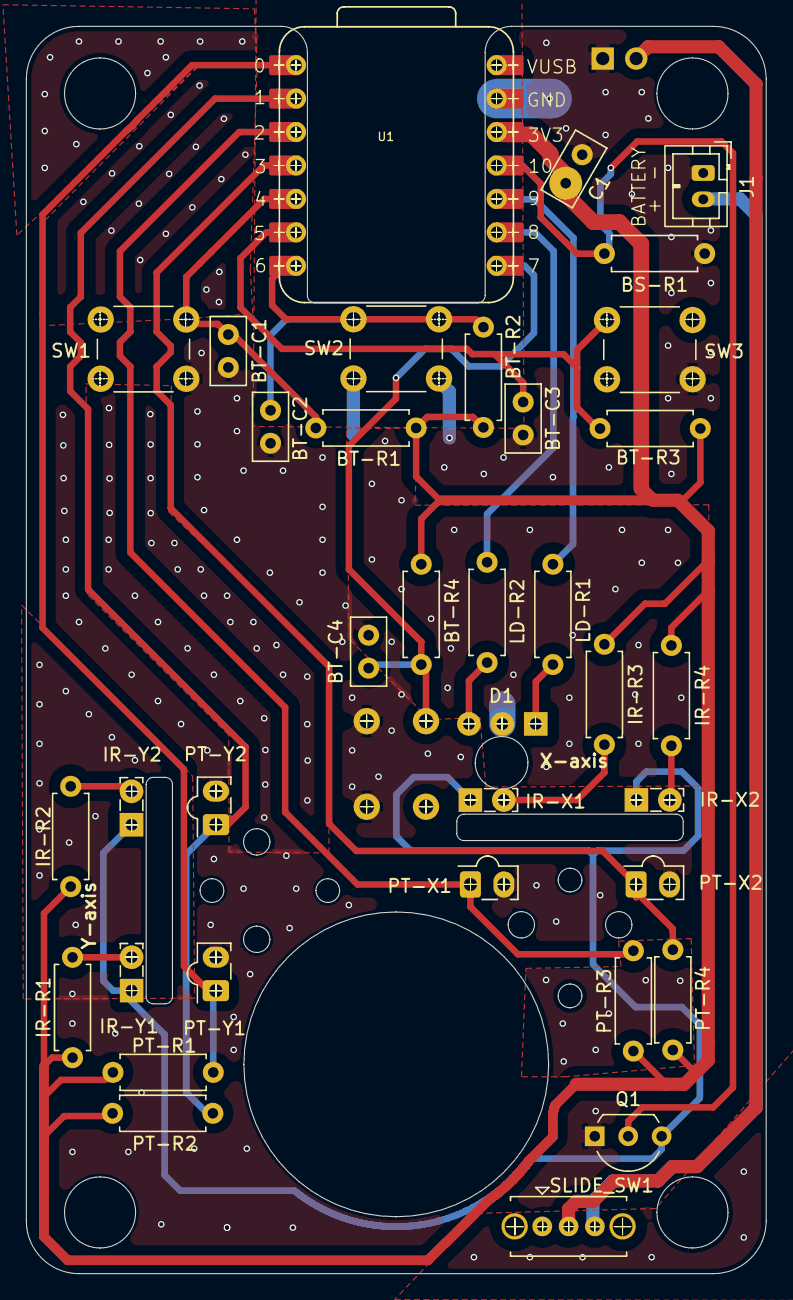
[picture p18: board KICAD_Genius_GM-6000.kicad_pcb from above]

Board: 2 copper layers, 56.2 x 94.8 mm, 38 parts (1 on the bottom side), 22 nets.

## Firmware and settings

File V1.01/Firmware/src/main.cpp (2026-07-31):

// GENIUS GM-6000 BLE MOUSE
// Modular PlatformIO version
// Ball mouse + middle-hold scroll + air mouse + optimized idle/deep sleep

#include <Arduino.h>
#include "Config.h"
#include "Pins.h"
#include "MouseReport.h"
#include "IrPower.h"
#include "StatusLeds.h"
#include "Encoders.h"
#include "Buttons.h"
#include "ImuManager.h"
#include "Battery.h"
#include "BleMouse.h"
#include "UsbMouse.h"
#include "MouseOutput.h"
#include "PowerManager.h"
#include "BallMouse.h"
#include "AirMouse.h"
#include "EnergyProfiler.h"
#include "UsageStats.h"
#include "SystemManager.h"
#include "FactoryReset.h"

static uint8_t lastReportedButtons = 0;
static bool wasAirMouseActive = false;

// A mouse button that wakes the nRF52840 from System OFF is already held
// while setup() runs. Without this small queue that first press becomes the
// initial button state and is never sent as a HID click.
static uint8_t startupWakeButtons = 0;
static uint8_t startupWakeStage = 0; // 0=none, 1=send down, 2=send/reconcile up
static uint32_t startupWakeDownSentAt = 0;

static uint32_t lastBallImuPoll = 0;
static uint32_t lastAirImuPoll = 0;
static uint32_t lastImuWakePoll = 0;
static uint32_t lastStatusLedUpdate = 0;

static void handleButtonWakeSources()
{
    if (buttonsChanged()) {
        if (buttonLeftNewPress()) { usageStatsRecordButtonPress("LEFT"); powerWake("LEFT"); }
        if (buttonRightNewPress()) { usageStatsRecordButtonPress("RIGHT"); powerWake("RIGHT"); }
        if (buttonMiddleNewPress()) { usageStatsRecordButtonPress("MIDDLE"); powerWake("MIDDLE"); }
        powerRecordActivity();
    }

    if (multiHostNewPress()) {
        usageStatsRecordButtonPress("MULTI-HOST");
        powerWake("MULTI-HOST");
        powerRecordActivity();
    }
}

static void handleMovementWakeSource(bool movementActivity)
{
    if (movementActivity && !powerIsIdleSleep()) {
        powerWake("MOVEMENT");
        powerRecordActivity();
    }
}

static void sendImmediateButtonReportIfNeeded()
{
    if (!buttonsChanged()) {
        return;
    }

    const uint8_t currentButtons = buttonsCurrent();

    if (
        currentButtons != lastReportedButtons &&
        mouseOutputCanSend() &&
        powerCanSendMouseReport()
    ) {
        MouseReportData buttonReport{};
        buttonReport.buttons = currentButtons;
        mouseOutputSendReport(buttonReport);
        lastReportedButtons = currentButtons;
    }
}


static void serviceStartupWakeClick()
{
    if (startupWakeStage == 0 || startupWakeButtons == 0) {
        return;
    }

    if (!mouseOutputCanSend() || !powerCanSendMouseReport()) {
        return;
    }

    const uint8_t currentButtons = buttonsCurrent();

    if (startupWakeStage == 1) {
        // Preserve any buttons currently held and add the button that caused
        // the wake. This also works when the user released it before BLE had
        // finished reconnecting.
        MouseReportData report{};
        report.buttons = currentButtons | startupWakeButtons;
        mouseOutputSendReport(report);
        lastReportedButtons = report.buttons;
        startupWakeDownSentAt = millis();
        startupWakeStage = 2;
        return;
    }

    // Keep a genuine long press held. When it was released before the BLE
    // reconnection, create a short but valid release after the queued press.
    if ((currentButtons & startupWakeButtons) != 0) {
        return;
    }

    if (millis() - startupWakeDownSentAt < 20) {
        return;
    }

    if (lastReportedButtons & startupWakeButtons) {
        MouseReportData report{};
        report.buttons = currentButtons;
        mouseOutputSendReport(report);
        lastReportedButtons = report.buttons;
    }

    startupWakeButtons = 0;
    startupWakeStage = 0;
}

static void updateStatusLedsIfDue()
{
    const uint32_t now = millis();

    if (now - lastStatusLedUpdate < STATUS_LED_UPDATE_INTERVAL_MS) {
        return;
    }

    lastStatusLedUpdate = now;

    statusLedsUpdate(
        powerIsIdleSleep(),
        mouseOutputConnected(),
        imuIsMouseOnBack(),
        batteryPercent()
    );
}

static void updateImuForActiveMode()
{
    const uint32_t now = millis();

    if (wasAirMouseActive) {
        if (now - lastAirImuPoll >= IMU_AIR_POLL_INTERVAL_MS) {
            lastAirImuPoll = now;
            energyProfilerImuPoll();
            imuUpdate();
        }
    } else {
        if (now - lastBallImuPoll >= IMU_BALL_POLL_INTERVAL_MS) {
            lastBallImuPoll = now;
            energyProfilerImuPoll();
            imuUpdateAccelOnly();
        }
    }
}

static void handleAirMouseModeTransition(bool airActive)
{
    if (airActive == wasAirMouseActive) {
        return;
    }

    airMouseReset();
    encodersReset();
    wasAirMouseActive = airActive;

    // Air mouse uses the gyro, but does not need the IR LEDs or encoders.
    // Ball mode powers the gyro down and only polls the accelerometer at 26 Hz.
    powerSetIrAllowedByMode(!airActive);
    encodersSetEnabled(!airActive);

    // The profile switch refreshes the IMU data, so align the poll timers.
    lastBallImuPoll = millis();
    lastAirImuPoll = millis();
}

void setup()
{
    systemManagerEarlyBegin();
    // XIAO nRF52840 Sense: LiPo charge current set to 100 mA.
    pinMode(22, OUTPUT);
    digitalWrite(22, LOW);

#if DEBUG_ENABLED || ENERGY_PROFILER_ENABLED
    Serial.begin(115200);
#endif

#if DEBUG_ENABLED
    const uint32_t serialStart = millis();
    while (!Serial && millis() - serialStart < 5000) {
        delay(10);
    }

    Serial.print("Firmware: ");
    Serial.println(FIRMWARE_VERSION_STRING);
#endif

    statusLedsBegin();
    irPowerBegin();
    buttonsBegin();

    // Hold left + middle + right continuously for five seconds during boot to
    // request a full reset of all resettable persistent runtime data.
    const bool factoryResetRequested = factoryResetRequestedAtBoot();

    // A System OFF wake is not electrically identical to reconnecting the
    // battery. Remove GPIO SENSE_LOW, wait for the held wake button to be
    // released, then start all input and BLE services from a clean state.
    // Keep the original wake click queued so it can be sent after reconnect.
    if (systemManagerWasSystemOffWake()) {
        startupWakeButtons = buttonsRecoverFromSystemOffWake();
        startupWakeStage = startupWakeButtons ? 1 : 0;
    } else {
        startupWakeButtons = 0;
        startupWakeStage = 0;
    }

    encodersBegin();

    const bool imuStartedSuccessfully = imuBegin();

    airMouseBegin();
    ballMouseBegin();

    // Start BLE/USB first so the BLE Battery Service exists before
    // the first battery percentage is published.
    mouseOutputBegin();

    if (factoryResetRequested) {
        factoryResetExecute();
    }

    batteryBegin();
    powerBegin();
    usageStatsBegin();
    systemManagerBegin(imuStartedSuccessfully);

    const bool initialAirActive = airMouseIsActive();
    wasAirMouseActive = initialAirActive;

    powerSetIrAllowedByMode(!initialAirActive);
    encodersSetEnabled(!initialAirActive);

    // Start from released when a wake button is queued, otherwise the first
    // press would again look as if it had already been reported.
    lastReportedButtons = startupWakeStage ? 0 : buttonsCurrent();

    const uint32_t now = millis();
    lastBallImuPoll = now;
    lastAirImuPoll = now;
    lastImuWakePoll = now;
    lastStatusLedUpdate = now;

    energyProfilerBegin(usbMouseHostMounted());
}

void loop()
{
    energyProfilerLoopBegin();

    batteryUpdate();
    mouseOutputUpdate();
    systemManagerUpdate();
    usageStatsProcessSerial();
    usageStatsUpdate(
        powerIsIdleSleep(),
        usbMouseHostMounted(),
        irLedsAreOn(),
        bleMouseConnected()
    );

    if (usbMouseModeChanged()) {
        const bool usbMode = usbMouseHostMounted();
        lastReportedButtons = buttonsCurrent();
        energyProfilerUsbModeChanged(usbMode);
    }

    energyProfilerUpdate();

    buttonsUpdate();

    // Buttons are handled before IMU, encoder and mouse calculations.
    // This gives clicks priority and immediately offers the HID report to USB/BLE.
    handleButtonWakeSources();
    serviceStartupWakeClick();
    sendImmediateButtonReportIfNeeded();

    if (powerIsIdleSleep()) {
        const uint32_t now = millis();

        // During idle, only the 26 Hz accelerometer is running.
        // No gyro reads, ball processing or air-mouse processing occur.
        if (now - lastImuWakePoll >= IMU_POLL_INTERVAL_MS) {
            lastImuWakePoll = now;

#if DEBUG_ENABLED && DEBUG_IMU
            Serial.println("Checking IMU wake");
#endif

            energyProfilerImuPoll();
            if (imuDetectPhysicalMovement()) {
#if DEBUG_ENABLED && DEBUG_IMU
                Serial.println("IMU WAKE DETECTED");
#endif
                powerWake("IMU");
            }
        }

        powerUpdate();
        updateStatusLedsIfDue();

        if (powerIsIdleSleep()) {
            // In the Adafruit nRF52 core delay() yields to tickless FreeRTOS,
            // allowing the CPU to sleep between BLE and timer events.
            energyProfilerBeforeDelay(IDLE_LOOP_DELAY_MS);
            delay(IDLE_LOOP_DELAY_MS);
            return;
        }
    }

    updateImuForActiveMode();

    const bool airActive = airMouseIsActive();
    handleAirMouseModeTransition(airActive);

    const uint8_t rawButtons = buttonsCurrent();
    const bool stableButtonChanged = buttonsChanged();
    const bool ballWorkPending =
        !airActive && (stableButtonChanged || ballMouseHasPendingWork(rawButtons));

    bool movementActivity = false;
    bool reportWasBuilt = false;
    MouseReportData report;

    if (airActive) {
        // Air mode must remain time-driven because gyro filtering needs a fixed cadence.
        report = airMouseUpdate(rawButtons, movementActivity);
        reportWasBuilt = true;
    } else if (ballWorkPending) {
        // Ball mode is event-driven: only consume encoder data when an ISR,
        // button transition or remaining scroll momentum requires work.
        report = ballMouseUpdate(rawButtons, movementActivity);
        reportWasBuilt = true;
    }

    handleMovementWakeSource(movementActivity);
    powerUpdate();

    if (reportWasBuilt) {
        const bool reportButtonChanged =
            report.buttons != lastReportedButtons;

        if (
            mouseOutputCanSend() &&
            powerCanSendMouseReport() &&
            (report.hasMotion() || reportButtonChanged)
        ) {
            mouseOutputSendReport(report);
            lastReportedButtons = report.buttons;
        }
    }

    updateStatusLedsIfDue();

    // Tickless FreeRTOS sleeps the CPU during delay(). Keep the fast cadence
    // while work is active, but wake less often when the ball mouse is quiet.
    if (airActive) {
        energyProfilerBeforeDelay(MAIN_LOOP_DELAY_MS);
        delay(MAIN_LOOP_DELAY_MS);
    } else if (ballWorkPending) {
        energyProfilerBeforeDelay(BALL_ACTIVE_LOOP_DELAY_MS);
        delay(BALL_ACTIVE_LOOP_DELAY_MS);
    } else {
        energyProfilerBeforeDelay(BALL_QUIET_LOOP_DELAY_MS);
        delay(BALL_QUIET_LOOP_DELAY_MS);
    }
}

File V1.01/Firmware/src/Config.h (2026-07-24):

#pragma once

// ============================================================================
// GM-6000 FIRMWARE CONFIGURATION
// ============================================================================
//
// Central configuration file for:
// - Debug output
// - USB and BLE HID
// - Ball mouse movement and scrolling
// - IR LED power saving
// - Sleep and wake behaviour
// - Battery monitoring
// - Status LEDs
// - Air mouse behaviour
//
// Change settings here instead of editing the implementation files.
// ============================================================================


// ============================================================================
// FIRMWARE VERSION
// ============================================================================
//
// Exposed through the BLE Device Information Service.
// Increase PATCH for bug fixes, MINOR for new compatible features,
// and MAJOR for incompatible changes.
//

#define FIRMWARE_VERSION_STRING "1.0.0"
#define FIRMWARE_HARDWARE_REV   "XIAO nRF52840 Sense"

// ============================================================================
// DEBUG CONFIGURATION
// ============================================================================
//
// DEBUG_ENABLED must be true before any individual debug category can print.
//
// Example:
//   DEBUG_ENABLED = true
//   DEBUG_USB     = true
//
// Set everything to false for normal release builds.
//

#define DEBUG_ENABLED       false

#define DEBUG_BLE           false
#define DEBUG_USB           false
#define DEBUG_SLEEP         false
#define DEBUG_BATTERY       false
#define DEBUG_IMU           false

// Optional runtime energy/work profiler. Enable temporarily while measuring
// through the Serial Monitor at 115200 baud, then set false for normal use.
#define ENERGY_PROFILER_ENABLED     false

// Lightweight long-term usage statistics with USB Serial commands.
// Statistics are saved to internal flash once per hour and at safe events.
#define USAGE_STATS_ENABLED          true



// ============================================================================
// SYSTEM RELIABILITY
// ============================================================================

#define SYSTEM_WATCHDOG_ENABLED              true
#define SYSTEM_WATCHDOG_TIMEOUT_MS            8000UL
#define BLE_SELF_HEAL_INTERVAL_MS             3000UL
#define CRITICAL_BATTERY_CHECK_INTERVAL_MS   10000UL
#define CRITICAL_BATTERY_SHUTDOWN_V             3.40f
#define CRITICAL_BATTERY_RECOVERY_V             3.50f
#define CRITICAL_BATTERY_CONFIRM_SAMPLES           3

// ============================================================================
// USB DEVICE CONFIGURATION
// ============================================================================
//
// Product and manufacturer names shown by the USB host.
//
// Windows may cache an old USB name. Remove the old device in Device Manager
// when changing these strings.
//

#define USB_PRODUCT_NAME      "Genius GM-6000 USB Mouse"
#define USB_MANUFACTURER_NAME "GM-6000 Revival Project"


// ============================================================================
// BLE CONFIGURATION
// ============================================================================
//
// BLE_DEVICE_NAME:
// Name shown during Bluetooth pairing.
//
// BLE_TX_POWER:
// Nordic nRF52840 transmit power in dBm.
// Common values: -40, -20, -16, -12, -8, -4, 0, 4, 8
// Higher values improve signal strength but use slightly more power.
//

#define BLE_DEVICE_NAME "Genius GM-6000 BLE mouse"
#define BLE_TX_POWER    8

// BLE connection interval units are 1.25 ms.
// Supervision-timeout units are 10 ms.
//
// Active profile:
//   interval 6   = 7.5 ms
//   timeout 200  = 2.0 s
//
// The experimental idle profile remains reserved but is not requested during
// normal operation. Earlier testing with a 500 ms interval caused Windows 11
// to return too slowly to the active profile, resulting in choppy movement.
#define BLE_ACTIVE_CONN_INTERVAL 6
#define BLE_ACTIVE_SUP_TIMEOUT   200
#define BLE_IDLE_CONN_INTERVAL   400   // 500 ms; reserved
#define BLE_IDLE_SUP_TIMEOUT     1200  // 12 s; reserved


// ============================================================================
// MOUSE OUTPUT SENSITIVITY
// ============================================================================
//
// Final movement scaling applied separately to BLE and USB reports.
//
// Examples:
//   1.00f = unchanged
//   1.10f = 10% faster
//   1.25f = 25% faster
//   0.90f = 10% slower
//
// These multipliers are applied after the normal ball-mouse calculations.
//

// Ball mouse
#define BLE_BALL_MOUSE_SPEED_MULTIPLIER 1.00f
#define USB_BALL_MOUSE_SPEED_MULTIPLIER 1.50f

// Air mouse
#define BLE_AIR_MOUSE_SPEED_MULTIPLIER 1.00f
#define USB_AIR_MOUSE_SPEED_MULTIPLIER 0.30f
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

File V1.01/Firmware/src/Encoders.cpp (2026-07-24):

#include "Encoders.h"
#include "Pins.h"
#include "Config.h"
#include "EnergyProfiler.h"
#include "UsageStats.h"

static volatile long xDelta = 0;
static volatile long yDelta = 0;
static volatile uint8_t lastXState = 0;
static volatile uint8_t lastYState = 0;
static bool encodersEnabled = false;
static volatile bool movementPending = false;

static const int8_t quadTable[16] = {
     0, +1, -1,  0,
    -1,  0,  0, +1,
    +1,  0,  0, -1,
     0, -1, +1,  0
};

static void xISR() {
    uint8_t state = (digitalRead(X_A) << 1) | digitalRead(X_B);
    uint8_t transition = (lastXState << 2) | state;
    int8_t movement = quadTable[transition];
    if (movement != 0) {
        xDelta += movement;
        movementPending = true;
        energyProfilerEncoderEventFromIsr();
    }
    lastXState = state;
}

static void yISR() {
    uint8_t state = (digitalRead(Y_A) << 1) | digitalRead(Y_B);
    uint8_t transition = (lastYState << 2) | state;
    int8_t movement = quadTable[transition];
    if (movement != 0) {
        yDelta += movement;
        movementPending = true;
        energyProfilerEncoderEventFromIsr();
    }
    lastYState = state;
}

void encodersReset() {
    noInterrupts();
    xDelta = 0;
    yDelta = 0;
    movementPending = false;
    lastXState = (digitalRead(X_A) << 1) | digitalRead(X_B);
    lastYState = (digitalRead(Y_A) << 1) | digitalRead(Y_B);
    interrupts();
}

void encodersSetEnabled(bool enabled) {
    if (enabled == encodersEnabled) return;

    if (enabled) {
        encodersReset();
        attachInterrupt(digitalPinToInterrupt(X_A), xISR, CHANGE);
        attachInterrupt(digitalPinToInterrupt(X_B), xISR, CHANGE);
        attachInterrupt(digitalPinToInterrupt(Y_A), yISR, CHANGE);
        attachInterrupt(digitalPinToInterrupt(Y_B), yISR, CHANGE);
        encodersEnabled = true;

#if DEBUG_ENABLED && DEBUG_SLEEP
        Serial.println("Encoders ON");
#endif
    } else {
        detachInterrupt(digitalPinToInterrupt(X_A));
        detachInterrupt(digitalPinToInterrupt(X_B));
        detachInterrupt(digitalPinToInterrupt(Y_A));
        detachInterrupt(digitalPinToInterrupt(Y_B));
        encodersReset();
        encodersEnabled = false;

#if DEBUG_ENABLED && DEBUG_SLEEP
        Serial.println("Encoders OFF");
#endif
    }
}

bool encodersHasPendingMovement() {
    return movementPending;
}

void encodersBegin() {
    pinMode(X_A, INPUT_PULLUP);
    pinMode(X_B, INPUT_PULLUP);
    pinMode(Y_A, INPUT_PULLUP);
    pinMode(Y_B, INPUT_PULLUP);

    encodersReset();
    encodersSetEnabled(true);
}

void encodersConsume(long &rawX, long &rawY) {
    noInterrupts();
    rawX = xDelta;
    rawY = yDelta;
    xDelta = 0;
    yDelta = 0;
    movementPending = false;
    interrupts();

    usageStatsRecordEncoderSteps(rawX, rawY);
}

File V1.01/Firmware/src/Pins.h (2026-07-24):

#pragma once
#include <Arduino.h>

#define IR_LED_POWER_PIN D10

#define X_A D2
#define X_B D3

#define Y_A D1
#define Y_B A0

#define BTN_LEFT       D4
#define BTN_RIGHT      D5
#define BTN_MIDDLE     D6
#define BTN_MULTI_HOST D7

#define LED_BAT_RED    D8
#define LED_BLE_BLUE   D9

#define READ_BAT_ENABLE_PIN 14
#define VBAT_ADC_PIN PIN_VBAT

// On-board BQ25101 ~CHG signal, active LOW, connected to nRF52840 P0.17.
#define CHARGE_STATUS_NRF_PIN 17

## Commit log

2026-05-10 First upload
    Unfinished work V0.1 status
    [Genius_GM-6000_Assy_V0.1.stp, Genius_GM-6000_BLE_LED_3009R1B2C-DSA_V0.1.stp, Genius_GM-6000_Ball_Lock_V0.1.stp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]
2026-07-24 Update README with assembly notes and release status
    Added assembly notes pictures and updated status to reflect V1.0 release.
2026-07-24 Update project title to include 'Wired USB'
2026-07-26 Revise BOM with updated PCB part number and notes
    Updated the part number for the custom PCB and clarified reused parts from the original GM-6000.
2026-07-26 Add Bill of Materials link to README
2026-07-31 Version 1.0.1 - Deep-sleep reconnect fix & Added Factory reset functionality
    ## Version 1.0.1
    ### Fixed
    - Fixed a deep-sleep wake issue that could prevent the mouse from functioning correctly after reconnecting over Bluetooth Low Energy (BLE).
    - Improved System OFF wake handling by correctly restoring button and input states after waking from deep sleep.
    - Improved overall wake-up reliability and BLE reconnection stability.
    ### Added
    - Added a three-button **Factory Reset** feature.
    - Factory Reset clears:
    - BLE bonding information
    - LittleFS / InternalFS
    - Saved settings
    - Usage statistics
    - Battery statistics
    - The mouse automatically reboots after the reset is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
    [Battery.cpp]
